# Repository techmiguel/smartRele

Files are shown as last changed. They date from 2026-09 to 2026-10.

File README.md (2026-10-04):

# SmartRele · rele-esp12f

**Single-channel Wi-Fi relay module based on the ESP-12F (ESP8266) for 110–120 VAC mains.**









<p align="center">
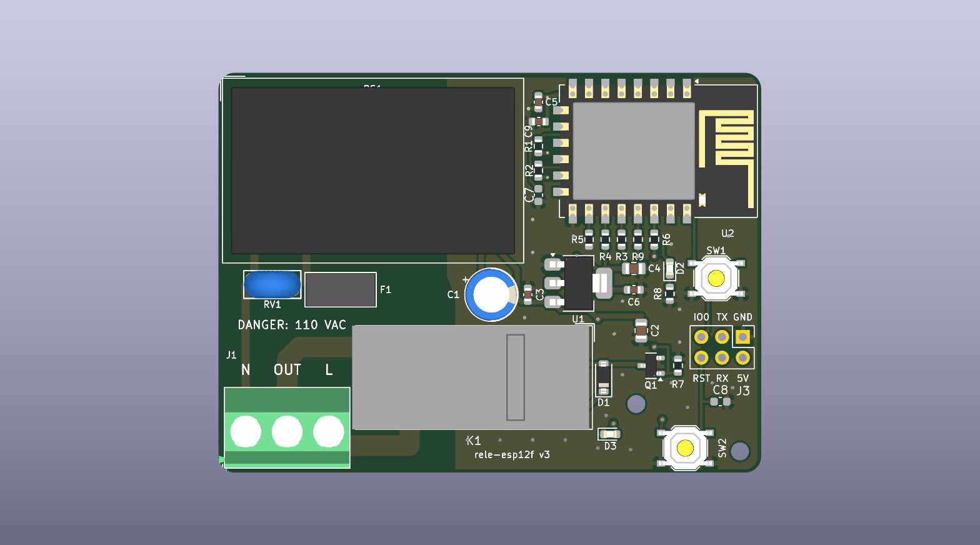
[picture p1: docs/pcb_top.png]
PCB render, top side
  
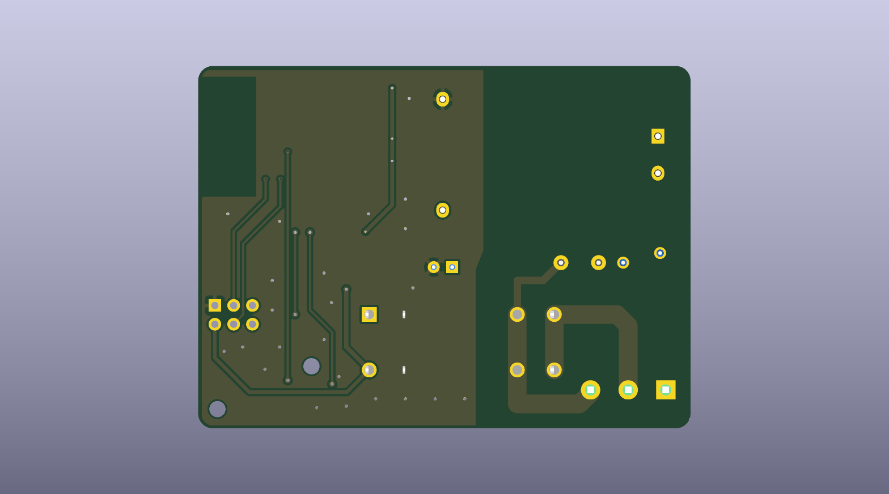
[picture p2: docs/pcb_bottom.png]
PCB render, bottom side
  
</p>

A 2-layer, **66.5 × 49 mm** board that switches a mains load of up to **10 A** from an ESP-12F. It is powered directly from the mains through an isolated HLK-PM01 supply and integrates input protection (time-lag fuse and varistor), a 16 A Omron G5RL power relay, status indicators and a programming header. All components sit on the top side, and the board is ready to be ordered **fully assembled from JLCPCB** (SMD and THT), with no hand soldering.

> [!WARNING]
> This design operates at **mains voltage**. Assembly, testing and installation must be carried out by qualified people. Read the [Safety](#safety) section before connecting the board.

---

## Table of contents
- [Features](#features)
- [Specifications](#specifications)
- [Architecture](#architecture)
- [Connectors and pinout](#connectors-and-pinout)
- [Repository layout](#repository-layout)
- [Manufacturing and assembly](#manufacturing-and-assembly)
- [Firmware](#firmware)
- [First firmware flashing](#first-firmware-flashing)
- [Enclosure](#enclosure)
- [Design verification](#design-verification)
- [Safety](#safety)
- [Documentation](#documentation)
- [License](#license)

## Features
- **ESP-12F** with the antenna at the board edge and a copper-free area underneath.
- **Omron G5RL-1A-E-HR relay** (SPST-NO, 16 A / 250 VAC) with 8 mm coil-to-contact separation (reinforced insulation per the manufacturer).
- **Strict mains / low-voltage zoning** enforced by custom design rules: 4 mm between mains and low voltage, 2 mm between mains nets. Measured minimum clearance: 4.35 mm.
- **Duplicated power path** on both sides (2 × 2.5 mm, 35 µm), sized for 10 A with a ~12 °C temperature rise (IPC-2221).
- **Input protection**: T500mA time-lag fuse (protects the supply) and 07D221K varistor.
- **Robust start-up**: RC delay on EN and RST, 10 µF + 100 nF decoupling next to the module, and the relay held open during reset.
- **Indicators** for relay (red) and Wi-Fi (blue); user/boot (GPIO0) and reset push buttons.
- **Programming** through a 2×3 header powered at 5 V; OTA updates afterwards.
- **Complete manufacturing package**: Gerbers, drill files, BOM and CPL ready for JLCPCB, with 3D models for every part.
- **3D-printable enclosure**, parametric and checked against the 3D model of the assembled board.

## Specifications

| Parameter | Value |
|---|---|
| Input voltage | 110–120 VAC, 50/60 Hz |
| Maximum load | 10 A resistive (trace limit; relay 16 A, terminal block 18 A) |
| Contact | SPST-NO, switches the line (L) |
| On-board supply | HLK-PM01, 5 V / 600 mA, isolated |
| Regulator | AMS1117-3.3 |
| Microcontroller | ESP8266 (ESP-12F module), Wi-Fi 802.11 b/g/n |
| Protection | F1 T500mA 250 V (supply branch) · RV1 07D221K |
| PCB | 66.5 × 49 × 1.6 mm, 2 layers, 35 µm copper |
| Assembly | Single-sided; 32 components, all factory-assembled |
| Mounting holes | 2 × M2 (MH1, MH2), in the low-voltage zone |

The full datasheet, with test conditions and the source of each value, is in [`docs/rele-esp12f_datasheet_user_guide.pdf`](docs/rele-esp12f_datasheet_user_guide.pdf).

## Architecture

```
 Power      J1:L ──────────► K1 contact (COM → NO) ──────────► J1:OUT ──► load

 Supply     J1:L ── F1 ── L_F ──► PS1 HLK-PM01 ──► +5 V ── U1 AMS1117 ──► +3.3 V ──► U2 ESP-12F
                          RV1 between L_F and N

 Control    +5 V ── K1 coil (D1 flyback diode) ── Q1 SS8050 ── GND
                                                   ▲
                                        GPIO5 (U2) ── R6 1 kΩ
```

- **Mains zone** (bottom left): J1, F1, RV1, K1 and the PS1 input.
- **Low-voltage zone** (right): U1 and its capacitors, relay driver, LEDs, push buttons, J3 and mounting holes. GND planes on both sides, restricted to this zone.
- **Top strip**: PS1 on the left and the ESP-12F with its antenna on the right edge.

The full schematic is in [`docs/schematic.pdf`](docs/schematic.pdf).

## Connectors and pinout

### J1 — Mains terminal block (3 poles, 5.08 mm pitch)
| Pin | Signal | Function |
|:-:|---|---|
| 1 | N | Neutral |
| 2 | OUT | Switched output to the load |
| 3 | L | Line input |

### J3 — Programming (2×3 header, 2.54 mm pitch)
```
 IO0   TX   GND(1)
 RST   RX   5V
```
Pin 1 (square pad) = GND; pin 2 = 5 V. Labeled on the silkscreen.

### ESP-12F
| GPIO | Function |
|---|---|
| GPIO5 | Relay (SS8050, R6 1 kΩ, R7 10 kΩ to GND) and relay LED (D2) |
| GPIO4 | Wi-Fi LED (D3) |
| GPIO0 | Push button SW1 (flashing mode / application use), 10 kΩ to 3.3 V |
| GPIO2 | 10 kΩ to 3.3 V (boot strap) |
| GPIO15 | 10 kΩ to GND (boot strap) |
| EN, RST | 10 kΩ to 3.3 V + 100 nF to GND; RST also to SW2 |

## Repository layout

```
.
├── rele-esp12f.kicad_pro      KiCad 10 project
├── rele-esp12f.kicad_sch      Schematic
├── rele-esp12f.kicad_pcb      PCB layout
├── rele-esp12f.kicad_dru      Custom design rules (mains isolation)
├── 3dmodels/                  STEP models missing from the KiCad library (K1, F1, SW1/SW2)
├── fabrication/               Production package for JLCPCB
│   ├── gerbers/               Gerbers and drill files (Excellon)
│   ├── gerbers_JLCPCB.zip     Gerbers + drill files + CPL, ready to upload
│   ├── BOM_JLCPCB.csv         Bill of materials with LCSC part numbers
│   └── CPL_JLCPCB.csv         Component placement list
├── docs/
│   ├── schematic.pdf
│   ├── rele-esp12f_datasheet_user_guide.pdf
│   ├── pcb_top.png · pcb_bottom.png
│   └── datasheets/            Datasheets of the key components
├── firmware/                  ESP8266 firmware (PlatformIO, Arduino core)
├── enclosure/                 3D-printable enclosure (FreeCAD, STEP, STL)
├── scripts/                   PDF datasheet generator
├── CHANGELOG.md
└── LICENSE
```

The custom 3D models are referenced through `${KIPRJMOD}/3dmodels/`, so the project opens without any extra path configuration.

## Manufacturing and assembly

1. Upload [`fabrication/gerbers_JLCPCB.zip`](fabrication/gerbers_JLCPCB.zip) to JLCPCB (2 layers, 1.6 mm).
2. Enable **PCB Assembly** (top side) and upload [`BOM_JLCPCB.csv`](fabrication/BOM_JLCPCB.csv) and [`CPL_JLCPCB.csv`](fabrication/CPL_JLCPCB.csv).
3. Before paying, check in the JLCPCB viewer that:
   - U2 and K1 sit on their pads;
   - the J1 wire entry faces the board edge;
   - J3 pin 1 lands on the square pad (GND);
   - every BOM line has a part selected.

THT parts are wave-soldered. The CPL uses the **pad center** (JLCPCB convention), not the body center; for U2 and K1 they differ. The drill holes of J1 (Ø1.5 mm) and RV1 (Ø1.0 mm) are matched to the actual parts.

### Power and THT components

| Ref. | Part | LCSC | Notes |
|---|---|---|---|
| PS1 | Hi-Link HLK-PM01 | C209903 | Isolated 5 V supply |
| K1 | Omron G5RL-1A-E-HR DC5 | C113250 | SPST-NO 16 A; 5 V coil, 80 mA |
| F1 | Reomax MTS0500A, T500mA 250 V | C2762401 | Time-lag, due to the PS1 inrush current |
| RV1 | Varistor 07D221K | C49072913 | For 110–120 VAC |
| C1 | 470 µF 10 V | C112505 | |
| J1 | KANGNEX WJ500V-5.08-3P | C72334 | 250 V / 18 A |
| J3 | 2×3 header, 2.54 mm | C65114 | Only used for the first flashing |

The full list is in the [BOM](fabrication/BOM_JLCPCB.csv).

### Regenerating the production files

With `kicad-cli` (KiCad 10), from the repository root:

```bash
kicad-cli pcb export gerbers --layers F.Cu,B.Cu,F.SilkS,B.SilkS,F.Mask,B.Mask,F.Paste,Edge.Cuts -o fabrication/gerbers/ rele-esp12f.kicad_pcb
```

```bash
kicad-cli pcb export drill --format excellon --excellon-units mm --excellon-separate-th --excellon-zeros-format decimal -o fabrication/gerbers/ rele-esp12f.kicad_pcb
```

```bash
kicad-cli pcb render --side top -w 1592 -h 904 --background opaque --quality basic --zoom 0.9954 -o docs/pcb_top.png rele-esp12f.kicad_pcb
```

```bash
kicad-cli pcb render --side bottom -w 1592 -h 904 --background opaque --quality basic --zoom 0.9954 -o docs/pcb_bottom.png rele-esp12f.kicad_pcb
```

These explicit options are needed because the plot settings stored in the board produce `.gbr` extensions and an unnecessary B.Paste layer. The ZIP contains the 11 files in `fabrication/gerbers/` plus `CPL_JLCPCB.csv`.

## Firmware

The [`firmware/`](firmware/) folder holds the board's own firmware (PlatformIO, Arduino core for ESP8266). In this version the relay is controlled over Wi-Fi only, from a built-in web page or a JSON REST API:

- manual on / off;
- state-change timer (turn on, off or toggle after 1 s – 7 days);
- cyclic ON/OFF routine (on for one period, off for another, repeated);
- up to 16 weekly schedules synchronised over NTP, with a configurable time zone.

On first boot it opens the `SmartRele-XXXXXX` setup access point; holding SW1 for 8 s erases the Wi-Fi settings. Setup, behaviour, API and security notes are in [`firmware/README.md`](firmware/README.md).

## First firmware flashing

1. **Disconnect the board from mains.**
2. Connect a USB-serial adapter with **3.3 V logic** to J3: TX↔RX, RX↔TX, GND, and its **5 V (VBUS)** output to the 5V pin.
3. Hold SW1 (GPIO0) while pressing and releasing SW2 (RST) to enter flashing mode.
4. Flash the firmware (`pio run -e esp12f -t upload` from `firmware/`). Later updates are done over the air (OTA).

J3 is powered at 5 V rather than 3.3 V for two reasons. The internal output-to-input diode of the AMS1117 would make the adapter also feed the 5 V rail. In addition, the 3.3 V pin of a typical adapter cannot supply the current peaks the ESP8266 draws while calibrating its radio.

Third-party firmware also works: the [datasheet](docs/rele-esp12f_datasheet_user_guide.pdf) includes example configurations for Tasmota and ESPHome.

## Enclosure

The [`enclosure/`](enclosure/) folder contains a two-part enclosure (base and screwed lid) for 3D printing in PETG or ASA/ABS. It is generated by a parametric FreeCAD script, and its interference with the 3D model of the assembled board is zero. Design, printing and assembly details are in [`enclosure/README.md`](enclosure/README.md).

<p align="center">
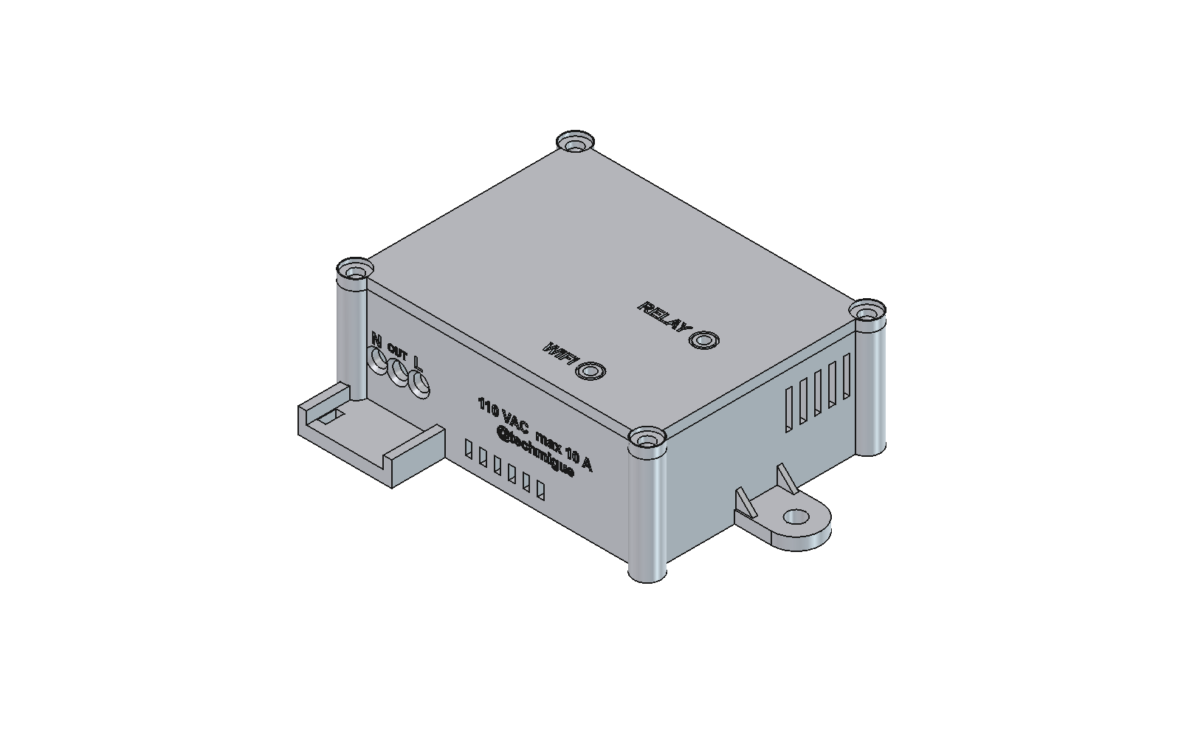
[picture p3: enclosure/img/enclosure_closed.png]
Closed enclosure
  
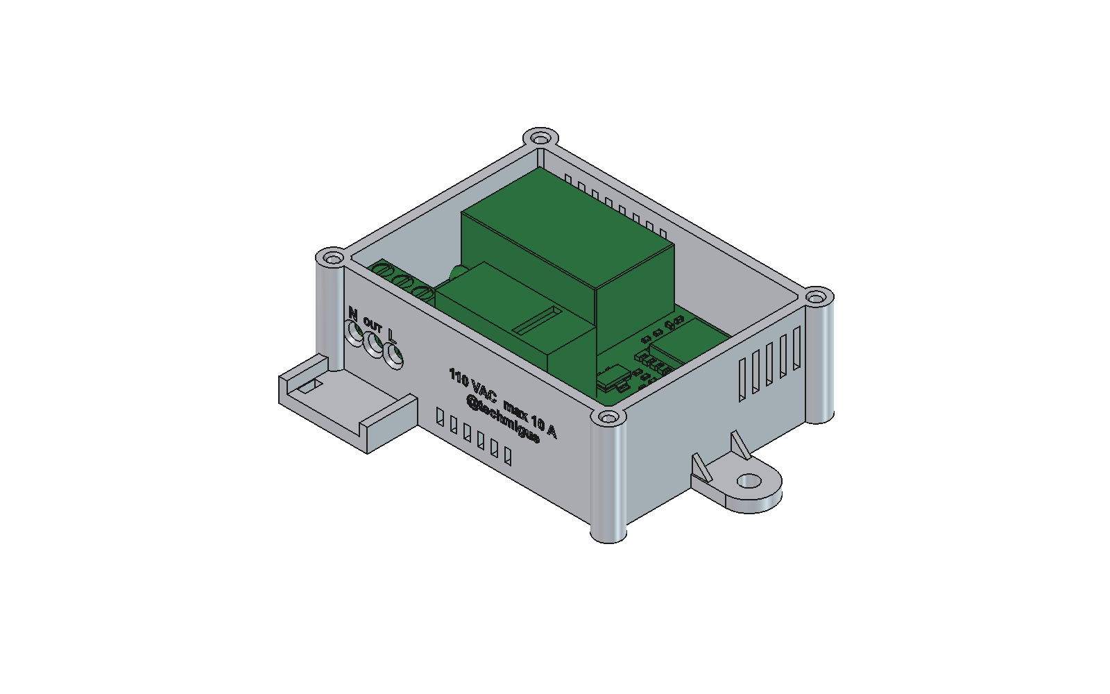
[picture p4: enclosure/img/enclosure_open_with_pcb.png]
Open enclosure with the board
  
</p>

## Design verification

Results with `kicad-cli` 10.0.5, with all zones refilled:

| Check | Errors | Warnings | Warning details |
|---|:-:|:-:|---|
| DRC | **0** | 29 | 23 footprints modified from the library (J1/RV1 drills and custom 3D models); 6 PS1/J1 silkscreen items next to the rounded corners |
| Schematic ↔ PCB parity | **0** | 34 | 32 LCSC/assembly fields not copied to footprints; 2 mounting holes without a symbol |
| ERC | **0** | 9 | Off-grid endpoints and symbols that differ from the library |
| Unconnected pads | **0** | — | |

None of the warnings affects manufacturing. Measured clearances: mains copper ↔ low voltage ≥ 4.35 mm on both sides; mains copper ↔ board edge ≥ 2.0 mm.

## Safety

- **110–120 VAC mains.** The 07D221K varistor is rated for that voltage. For 230 VAC it must be replaced (e.g. with a 07D471K). F1 is suitable for both voltages.
- **The load current does not flow through F1**, which only protects the supply. Install a circuit breaker or fuse of **≤ 10 A** upstream, dedicated to this output. An on-board fuse would not have enough breaking capacity for a mains short circuit.
- **Never connect J3 while the board is connected to mains.**
- Mount the board in an **insulating enclosure**: mains copper is 2 mm from the board edge.
- Use only **MH1 and MH2** (low-voltage zone) for metal hardware: M2 screws with a head or washer of Ø ≤ 5 mm.
- The printed enclosure provides mechanical and contact protection, but it is **not certified**. For a permanent installation, print it in a flame-retardant material or place it inside an approved electrical junction box.

## Documentation

| Document | Contents |
|---|---|
| [Datasheet and user guide](docs/rele-esp12f_datasheet_user_guide.pdf) | Specifications, operation, installation and design rationale |
| [Schematic](docs/schematic.pdf) | Full schematic in PDF |
| [Datasheets](docs/datasheets/) | Omron G5RL, AMS1117, ESP8266EX, ESP-WROOM-02 and the Espressif hardware design guidelines |
| [Changelog](CHANGELOG.md) | Hardware revisions and the rationale behind each change |
| [Enclosure](enclosure/README.md) | Enclosure design, printing and assembly |

The datasheet is regenerated with `python scripts/generate_datasheet.py` (requires ReportLab, PyMuPDF, Pillow and `kicad-cli`).

## License

Hardware released under the **CERN Open Hardware Licence v2 – Weakly Reciprocal** ([CERN-OHL-W-2.0](LICENSE)).

Inspired by [aman983/ESP-01S_Relay_Module](https://github.com/aman983/ESP-01S_Relay_Module). This is a new design and contains no files from the original.

---

© 2026 [@techmigue](https://github.com/techmiguel)

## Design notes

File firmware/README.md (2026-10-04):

# SmartRele firmware · rele-esp12f

Firmware v1.0.0 for the rele-esp12f board (ESP-12F / ESP8266). The relay is **controlled over Wi-Fi only**, from a built-in web interface or through a JSON REST API:

- **Manual on / off.**
- **State-change timer**: after a delay (1 s to 7 days) it turns the relay on, off or toggles it.
- **Cyclic ON/OFF routine**: on for one period and off for another, repeated indefinitely.
- **Weekly schedules**: up to 16 rules of the form "at HH:MM, on these days, turn on/off/toggle".

Push button SW1 does not control the relay in this version: it only erases the Wi-Fi settings.

## Hardware used

| GPIO | Function | Active level |
|---|---|---|
| GPIO5 | Relay K1 (through Q1) and red LED D2 | High |
| GPIO4 | Blue LED D3 (Wi-Fi status) | High |
| GPIO0 | Push button SW1 (R3 to 3.3 V) | Low |

Pins checked against the schematic netlist. R7 (10 kΩ to GND) keeps the relay open while GPIO5 is high-impedance (reset, boot and flashing); the firmware also drives the pin low as its very first instruction.

## Build and flash

Requires [PlatformIO](https://platformio.org/) (CLI or the VS Code extension). From this folder:

```bash
pio run -e esp12f
```

First flashing through header J3 (see the [main README](../README.md#first-firmware-flashing): board **disconnected from the mains**, 3.3 V USB-serial adapter, J3 powered at 5 V, hold SW1 while releasing SW2):

```bash
pio run -e esp12f -t upload
```

Serial monitor (115200 baud), useful to see the IP address and relay events:

```bash
pio device monitor
```

### Over-the-air updates (OTA)

Once the device is on the network there are two options, both protected by the admin password:

- **Browser**: *System → Update firmware* (`http://<device>/update`) and upload `.pio/build/esp12f/firmware.bin`.
- **PlatformIO** (ArduinoOTA): set the environment variable `SMARTRELE_PASS` to the admin password and run:

```bash
pio run -e esp12f_ota -t upload --upload-port smartrele-xxxxxx.local
```

The relay keeps its state while the update is written. The restart that follows briefly releases it, and then the *state at power-up* setting (or the cyclic routine, if it was active) is applied.

## Getting started

1. With no network configured, the device creates the access point **`SmartRele-XXXXXX`** (password `smartrele`). The blue LED blinks fast.
2. Join it from a phone. The setup page opens by itself; if it does not, browse to `http://192.168.4.1`.
3. Under *Settings*, set an **admin password** (user `admin`, 8–32 characters) and the time zone.
4. Under *Wi-Fi network*, pick the network, enter its password and press *Save and restart*.
5. The device joins the network (blue LED steady) and is reachable at `http://smartrele-xxxxxx.local/` (mDNS) or at the IP address the router assigns (shown on the serial monitor and in the router).

`XXXXXX` is the chip ID in hexadecimal, different on every board.

If the network is unavailable for 60 s, the access point opens again (the device keeps retrying the network) so the settings can be changed. It closes as soon as the network is back and nobody is connected to it.

**Erasing the Wi-Fi network**: hold SW1 for **8 s** (from 3 s on, the blue LED blinks very fast). The device restarts in access point mode. Schedules and the password are kept; to erase everything use *Factory reset* in the web interface.

### Blue LED (D3)

| Pattern | Meaning |
|---|---|
| Steady | Connected to the Wi-Fi network |
| Short flash every second | Looking for the network |
| Fast blink (2 Hz) | Setup access point active |
| Very fast blink | SW1 held: at 8 s the network is erased |

The red LED (D2) is wired in parallel with the relay driver: lit = relay closed.

## Behaviour

### Priorities between automations

| Command | Cyclic routine | Timer |
|---|---|---|
| Manual (web/API) | Stops it | Keeps running |
| Weekly schedule | Stops it | Keeps running |
| Start timer | Stops it | — |
| Start cyclic routine | — | Cancels it |

The timer and the cyclic routine cannot be active at the same time. When the timer expires it runs its action once.

### Time and schedules

- The time comes from **NTP** (`pool.ntp.org` by default) and is converted to local time with the configured **POSIX time zone** (the web interface lists those of Latin America, the US and Europe; any other can be typed in). The default is UTC.
- Without Internet access (for example, using only the access point) the web page sends the browser time when it opens. NTP time always takes precedence.
- Schedules do not run until the time is valid; the timer and the cyclic routine do, because they only use the internal clock.
- Each schedule runs once in its minute. After a restart it only runs if the device boots within the first 10 s of that minute. Schedules missed during a power cut are not caught up.
- When daylight saving time ends, a schedule inside the repeated hour may run twice.

### After a power cut

| Situation when power returns | Behaviour |
|---|---|
| Cyclic routine active | Resumes, starting with the ON phase |
| *State at power-up* = Off (default) | Relay open |
| = On | Relay closed |
| = Last state | State before the power cut |

The timer does **not** survive a restart. Schedules, the cyclic routine and the settings are stored in flash (LittleFS). The last relay state is only written when it changes, and never during the cyclic routine, to avoid wearing out the flash.

### Limits

| Parameter | Range |
|---|---|
| Timer | 1 s – 7 days |
| Cyclic routine phase | 5 s – 24 h |
| Schedules | 16 |

The 5 s minimum per phase prevents absurdly fast switching, but it is not enough for the relay to last: the Omron datasheet guarantees **50,000–100,000 electrical operations** at rated load (depending on the model). A 5 s ON / 5 s OFF routine makes 360 operations per hour and would use up 50,000 in less than a week; a 10 min ON / 50 min OFF routine would take more than five years. Choose phases as long as the application allows.

## REST API

All routes take and return JSON. When an admin password is set, **HTTP Digest** authentication is used with user `admin`. Examples with `curl`:

```bash
curl --digest -u admin:PASSWORD http://smartrele-xxxxxx.local/api/status
```

```bash
curl --digest -u admin:PASSWORD -X POST -H "Content-Type: application/json" -d '{"action":"on"}' http://smartrele-xxxxxx.local/api/relay
```

| Method and route | Body | Function |
|---|---|---|
| `GET /api/status` | — | Full status: relay, timer, routine, schedules, next event, time, Wi-Fi and system |
| `POST /api/relay` | `{"action":"on"\|"off"\|"toggle"}` | Direct command |
| `POST /api/timer` | `{"seconds":1800,"action":"off"}` | Starts the timer (`action` defaults to `off`) |
| `DELETE /api/timer` | — | Cancels the timer |
| `POST /api/cycle` | `{"on":600,"off":3000}` | Starts the cyclic routine (seconds) |
| `DELETE /api/cycle` | — | Stops the cyclic routine |
| `GET /api/schedules` | — | List of schedules |
| `POST /api/schedules` | `{"time":"07:30","days":62,"action":"on","enabled":true}` | Adds a schedule |
| `PUT /api/schedules?id=N` | Any field of the above | Modifies schedule N (0-based index) |
| `DELETE /api/schedules?id=N` | — | Deletes schedule N |
| `GET /api/config` | — | Settings (without passwords) |
| `POST /api/config` | `{"name","tz","ntp","powerOn":0\|1\|2,"adminPass"}` | Changes settings; every field is optional |
| `POST /api/time` | `{"epoch":1767225600}` | Sets the clock when there is no NTP |
| `GET /api/wifi/scan` | — | Scans for networks (replies 202 while scanning) |
| `POST /api/wifi` | `{"ssid":"...","pass":"..."}` | Stores the network and restarts |
| `POST /api/reboot` | — | Restarts |
| `POST /api/factory-reset` | — | Erases all settings and restarts |

`days` is a bit mask with Sunday in bit 0: Monday to Friday = 62, weekends = 65, every day = 127.

Changing the admin password restarts the device, because ArduinoOTA and `/update` read it at boot.

## Security

- **Always set an admin password.** Without it, anyone on the network (or on the access point, whose password is public) can switch the relay.
- The web interface uses plain HTTP. Digest authentication does not send the password in clear text, but the rest of the traffic is unencrypted: use it only on your local network and do not expose it to the Internet by forwarding ports on the router.
- Passwords are stored unencrypted in the module flash. Anyone with physical access to the board can read them.
- **Never connect the serial adapter to J3 while the board is connected to the mains.**

## Layout

```
firmware/
├── platformio.ini     esp12f (serial) and esp12f_ota (network) environments
└── src/
    ├── main.cpp       Start-up and main loop
    ├── board.h        Pin assignment
    ├── settings.*     Persistent settings (LittleFS, JSON)
    ├── relay.*        Relay, timer and cyclic routine
    ├── scheduler.*    Time (NTP / time zone) and weekly schedules
    ├── network.*      Wi-Fi, access point, captive portal, mDNS, OTA, LED and SW1
    ├── web.*          HTTP server and REST API
    └── web_ui.h       Embedded web interface
```

Dependencies: Arduino core for ESP8266 (PlatformIO `espressif8266` platform) and [ArduinoJson](https://arduinojson.org/) 7, which PlatformIO downloads automatically.

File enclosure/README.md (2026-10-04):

# 3D-printable enclosure — rele-esp12f v3

Two-part enclosure: base and screwed lid. Designed in FreeCAD from the real 3D model of the assembled PCB.

<p align="center">
  Closed enclosure
  Open enclosure with the PCB
</p>
<p align="center">
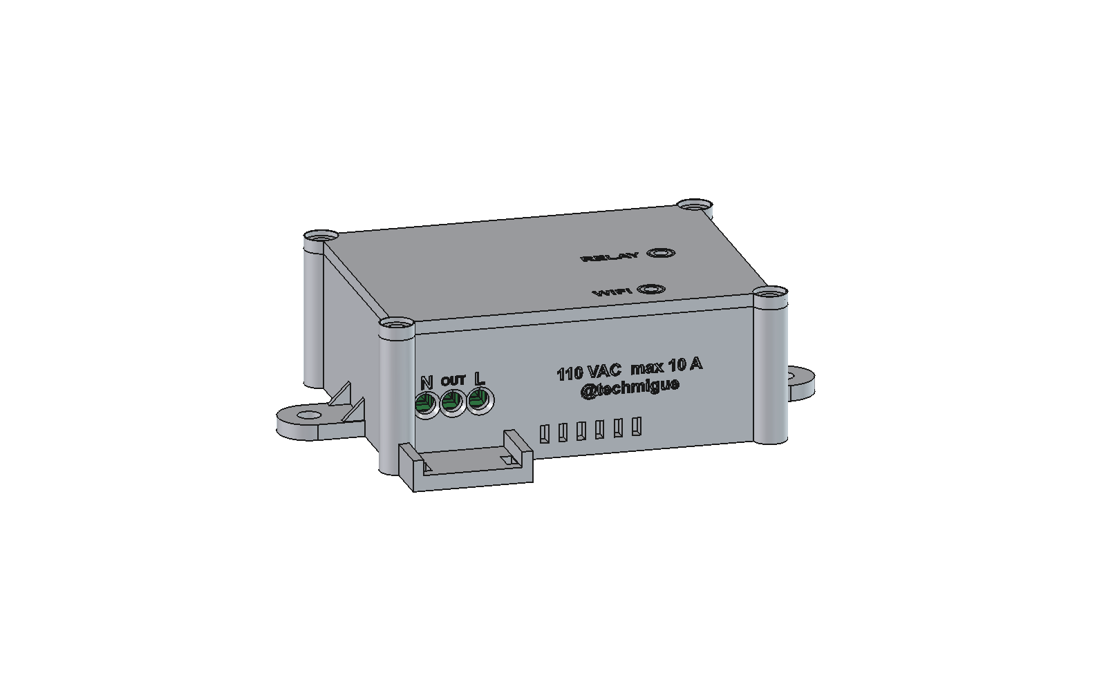
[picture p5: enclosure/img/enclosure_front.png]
Front view: cable entries and labels
  
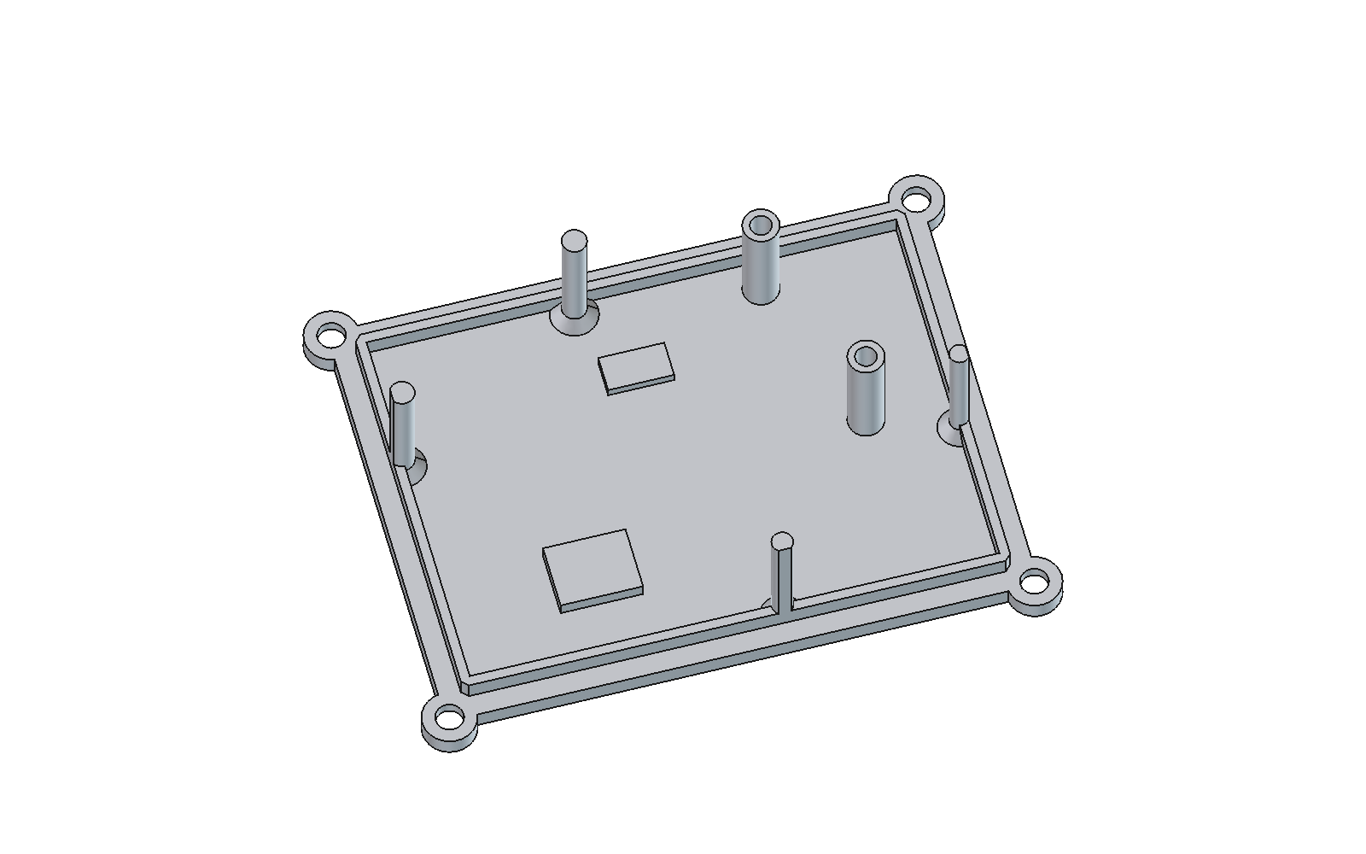
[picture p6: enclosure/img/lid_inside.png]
Inside of the lid: hold-down posts and light pipes
  
</p>

## Files
| File | Contents |
|---|---|
| `stl/enclosure_base.stl` | Base, already oriented for printing (floor on the bed). |
| `stl/enclosure_lid.stl` | Lid, already flipped (top face on the bed). |
| `enclosure_rele-esp12f.FCStd` | FreeCAD document with the parts in assembly position and the reference PCB. |
| `enclosure_rele-esp12f_assembly.step` | Base and lid in assembly position, without the PCB. |
| `rele-esp12f_pcb.step` | Assembled PCB exported from KiCad. Used to check the fit. |
| `generate_enclosure.py` | Parametric script that generates all of the above. |
| `img/` | Renders: closed, open with PCB, front, top, bottom and lid inside. |

To regenerate, from the repository root:
```bash
kicad-cli pcb export step --subst-models --force --user-origin 100x149mm -o enclosure/rele-esp12f_pcb.step rele-esp12f.kicad_pcb
```
```bash
freecadcmd enclosure/generate_enclosure.py
```
It can also be run from the FreeCAD Python console (with the repository root as the working directory): `exec(open(r"enclosure/generate_enclosure.py", encoding="utf-8").read())`.

## Dimensions
- Outside: 77.5 × 60 × 28.5 mm (box only; 101.9 × 70.2 mm including the mounting tabs and the strain-relief apron).
- Inside: 67.1 × 49.6 mm, i.e. the PCB plus 0.3 mm of clearance per side. 2.4 mm walls, 2.0 mm floor and 2.5 mm lid.
- PCB 5 mm above the floor. The longest THT leads (PS1) protrude 3.3 mm below the board, leaving a 1.7 mm air gap.
- Ceiling 1.7 mm above relay K1, the tallest part (15.7 mm above the PCB).

## Design criteria
- **Measured fit, not estimated.** Every dimension comes from the STEP exported by KiCad. The script checks the intersection of each part with the 87 solids of the assembled PCB: the interference volume is **0**. J3 has no 3D model in the library, so it was checked by hand: its pins reach about 17 mm and the lid starts at 23.5 mm (skirt).
- **PCB retention.** The board only has two mounting holes (MH1 and MH2), both in the bottom-right corner. With only two screws the board could rotate or lift on the mains side. Therefore:
  - Below, it rests on a 1.5 mm perimeter ledge (supporting 1.2 mm of the board edge), on the M2 standoffs of MH1/MH2 and on two pillars located right under SW1 and SW2, so the board does not flex when they are pressed with the lid removed.
  - Above, four lid posts come down to 0.2 mm from the PCB in component-free areas: left edge between J1 and PS1, top edge between PS1 and the ESP, bottom edge under K1 and right edge next to SW1. Two more stops sit 0.5 mm above PS1 and K1. Even if the screws loosen, the board cannot move more than 0.2 mm.
  - Metal screws only go through MH1/MH2. These holes are in the low-voltage zone, as required by the PCB README.
- **Screwed lid (4 × M3), not snap-fit.** On mains equipment, opening the enclosure must require a tool. The screw bosses are outside the PCB outline, 0.64 mm from its rounded corners. A 2.5 mm skirt centers the lid on the base.
- **Mains entry.** Three Ø3.8 mm holes with an outer countersink, aligned with the J1 wire entries. They were measured on the 3D model: center 5.1 mm above the PCB bottom face and 5.08 mm pitch. They are labeled N · OUT · L, matching the terminal block. In front there is an apron with two slots for a cable tie that provides strain relief: pulling the cable must never reach the terminal block.
- **No buttons on the lid.** SW1 (GPIO0) and SW2 (RST) are for debugging only: they stay inside and are pressed with the lid removed. Every hole and moving part removed from a mains enclosure is one less entry path for dust or objects. If the firmware used SW1 to toggle the relay by hand, a guide and a plunger above SW1 would have to be added to the lid.
- **LEDs.** D2 and D3 are 0603 SMD parts, 1.1 mm above the PCB. Ø2.6 mm light pipes come down from the lid to 1.5 mm above each LED, so the light of one LED is not visible through the other's hole. The holes stay above the LEDs, which are placed diagonally (7.3 mm in X and 20.3 mm in Y). To keep the marking tidy without moving them, the same module is repeated for each LED:
  - an engraved ring concentric with the hole, from Ø4.2 to Ø5.2 mm;
  - the label (RELAY / WiFi), same size (2.6 mm), right-aligned at the same distance from the ring and vertically centered on the hole.
  For better visibility, the pipe can be filled with a drop of clear resin or a piece of clear 1.75 mm filament.
- **Convection cooling.** Air enters through low slots at the front (below the PCB, next to the relay) and leaves through high slots at the back (above PS1) and on the right side. All slots are **1.5 mm** wide, so a 2.5 mm probe cannot pass (IP3X in that respect; not tested).
- **Antenna.** Only plastic covers the ESP-12F antenna; there are no screws or metal parts in that area. The mounting tabs are at both ends: the right-hand hole is 11.7 mm from the PCB edge, at mid-height of the board.

## Labels (engraved 0.5–0.6 mm deep)
- Lid: only RELAY and WiFi, next to their LEDs.
- Front: N · OUT · L above the cables and, below, on two lines, "110 VAC  max 10 A" and "@techmigue".
- Bottom: "Smart Rele" (product name), readable when the enclosure is turned over.

## Printing
- **Material: PETG or ASA/ABS.** Not PLA: inside the enclosure, PS1 and the relay coil (~0.5 W) produce heat, and PLA deforms from about 55 °C.
- 0.2 mm layers, 4 perimeters (the 2.4 mm walls come out solid), 25–30 % gyroid infill. **No supports needed**: all overhangs are bridges of ≤ 3.8 mm or 45° chamfers.
- The STL meshes were verified to be closed, with no non-manifold edges and no self-intersections.

## Assembly
Hardware: 4 × M3×10 self-tapping (lid), 2 × M2×6 self-tapping (PCB), 2 × M4 to mount the enclosure and 1 × 3.6 mm cable tie.
1. Screw the PCB to the base through MH1 and MH2 (M2×6, do not overtighten: it is plastic).
2. Pass the cables through the front holes and tighten them in J1 (N · OUT · L, left to right seen from the front). Secure them to the apron with the cable tie.
3. Close the lid and fit the 4 M3 screws.

## Safety notes (read)
- Common filaments (PETG, ASA, ABS) are **not self-extinguishing** (not UL94 V-0). For a permanent mains installation, the correct practice is one of:
  - printing in a flame-retardant material (PC-FR, ABS-FR or PETG V0);
  - placing this enclosure inside an approved electrical junction box.
  This enclosure provides mechanical and contact protection, but it is not certified.
- **Do not connect the USB-serial adapter (J3) while the board is connected to mains.** J3 is deliberately left inside the enclosure: it is only used with the lid removed and mains disconnected.
- Overcurrent protection for the load must still be installed upstream: a circuit breaker or fuse of ≤ 10 A (see the project README).

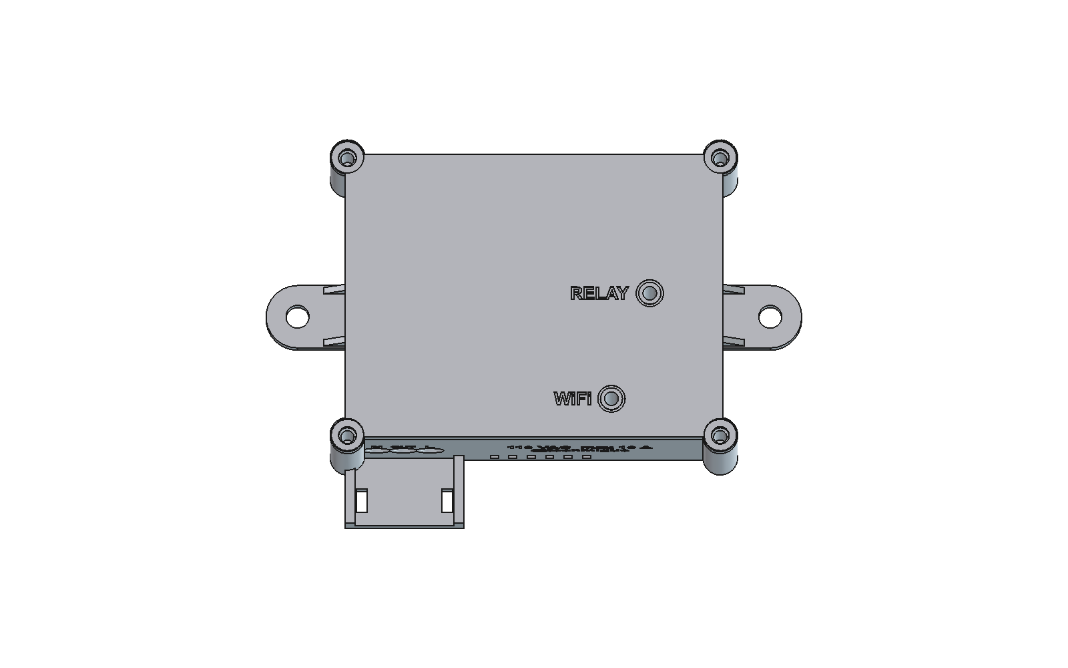
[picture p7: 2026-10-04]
enclosure/img/enclosure_top.png

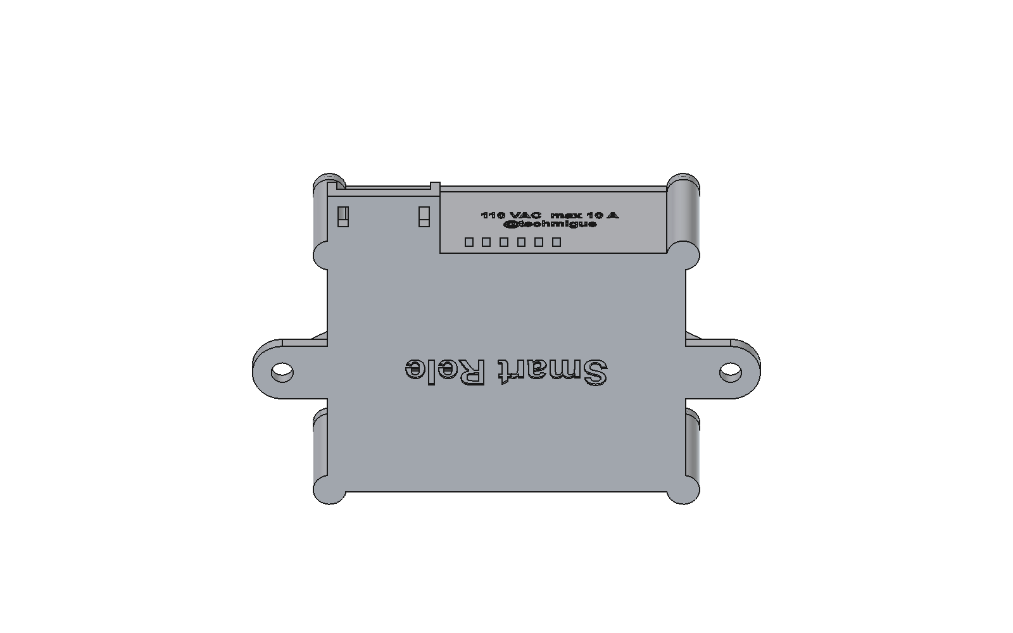
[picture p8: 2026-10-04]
enclosure/img/enclosure_bottom.png

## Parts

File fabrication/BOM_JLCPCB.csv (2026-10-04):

Comment | Designator | Footprint | LCSC Part #
22uF 10V | C2,C4 | C_0805_2012Metric | C45783
10uF 10V X5R | C9 | C_0603_1608Metric | C19702
100nF | C3,C5,C6,C7,C8 | C_0603_1608Metric | C14663
1N4148W | D1 | D_SOD-123 | C81598
LED relay (red) | D2 | LED_0603_1608Metric | C2286
LED WiFi (blue) | D3 | LED_0603_1608Metric | C51933294
SS8050 | Q1 | SOT-23 | C2150
10k | R1,R2,R3,R4,R5,R7 | R_0603_1608Metric | C25804
1k | R6,R8 | R_0603_1608Metric | C21190
220 | R9 | R_0603_1608Metric | C22962
TS-1187A | SW1,SW2 | SW_Push_1P1T_XKB_TS-1187A | C318884
AMS1117-3.3 | U1 | SOT-223-3_TabPin2 | C6186
470uF 10V | C1 | CP_Radial_D6.3mm_P2.50mm | C112505
T500mA 250V (Reomax MTS0500A; time-lag) | F1 | Fuse_Littelfuse_395Series | C2762401
G5RL-1A-E-HR DC5 (Omron, 16 A, SPST-NO) | K1 | Relay_SPST_Omron_G2RL-1A-E | C113250
HLK-PM01 | PS1 | Converter_ACDC_Hi-Link_HLK-PMxx | C209903
07D221K | RV1 | RV_Disc_D7mm_W3.4mm_P5mm | C49072913
ESP-12F | U2 | ESP-12E | C82891
N / L_OUT / L_IN (terminal block 3P 5.08 mm) | J1 | TerminalBlock_Phoenix_MKDS-1,5-3-5.08_1x03_P5.08mm_Horizontal | C72334
PROG (header 2x3 2.54 mm) | J3 | PinHeader_2x03_P2.54mm_Vertical | C65114

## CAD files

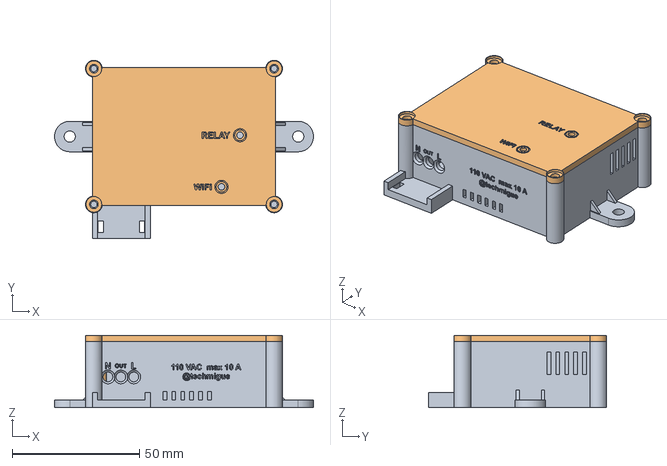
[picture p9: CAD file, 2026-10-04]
enclosure/enclosure_rele-esp12f_assembly.step
101.9 x 70.2 x 28.5 mm

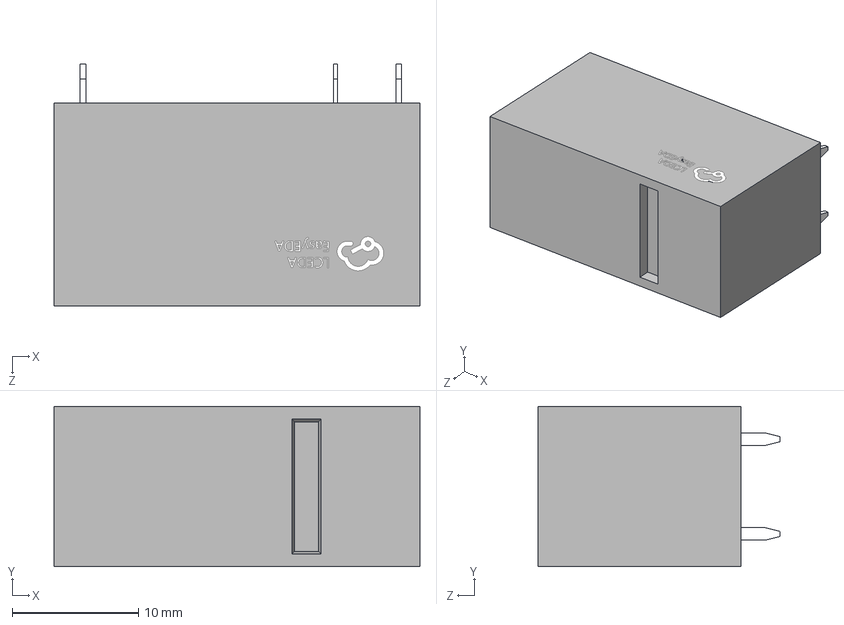
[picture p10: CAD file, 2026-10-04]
3dmodels/Relay_Omron_G5RL-1A-E-HR_C113250.step
29.0 x 12.7 x 19.2 mm

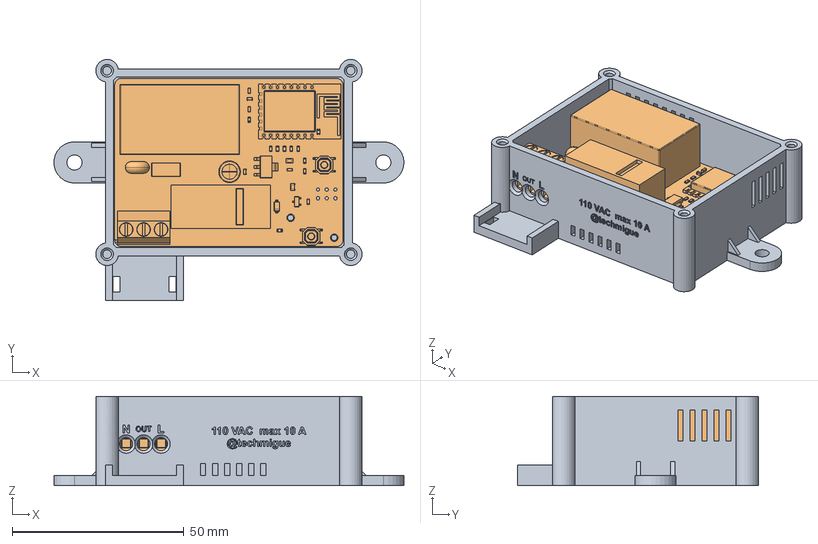
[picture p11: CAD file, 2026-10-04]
enclosure/enclosure_rele-esp12f.FCStd
101.9 x 70.2 x 26.0 mm
Base
PCB_reference

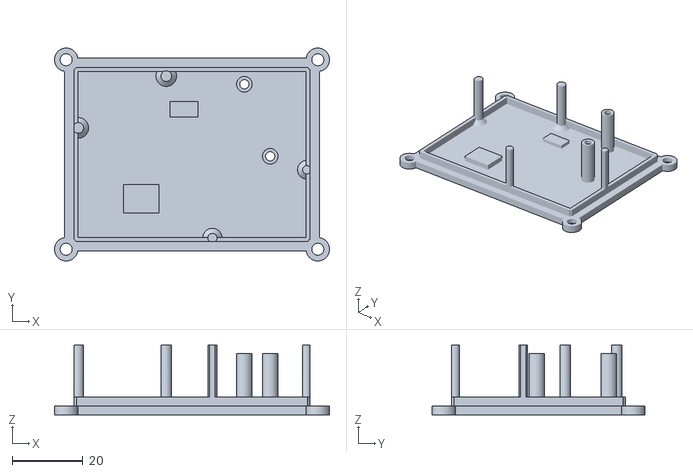
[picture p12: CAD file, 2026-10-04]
enclosure/stl/enclosure_lid.stl
77.5 x 60.0 x 19.7

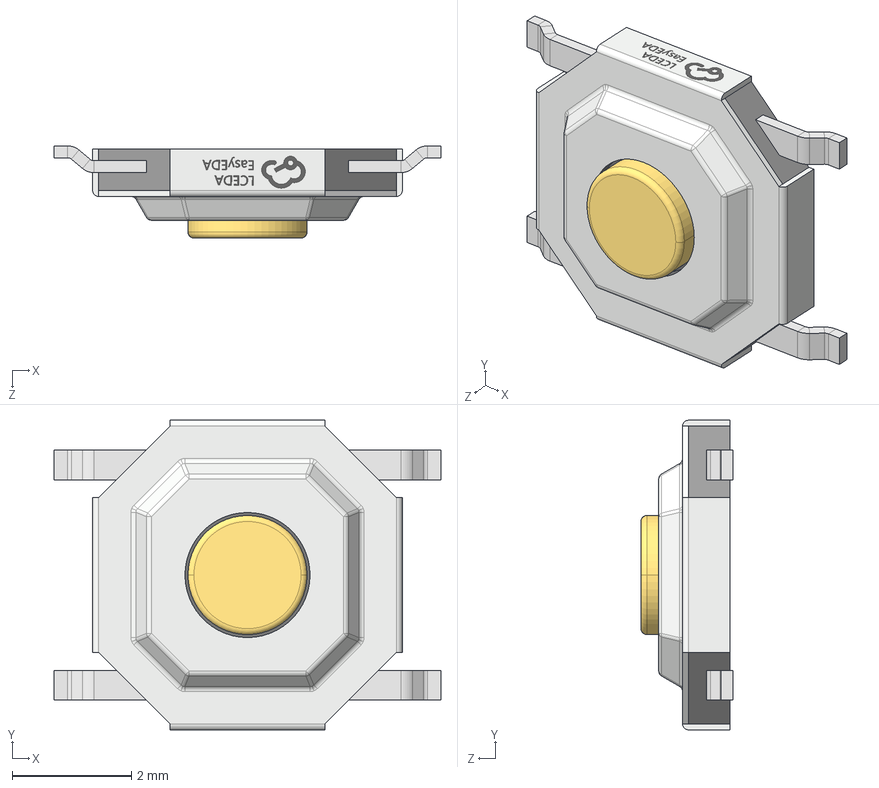
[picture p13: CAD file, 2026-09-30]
3dmodels/SW_TS-1187A_C318884.step
6.50 x 5.20 x 1.55 mm

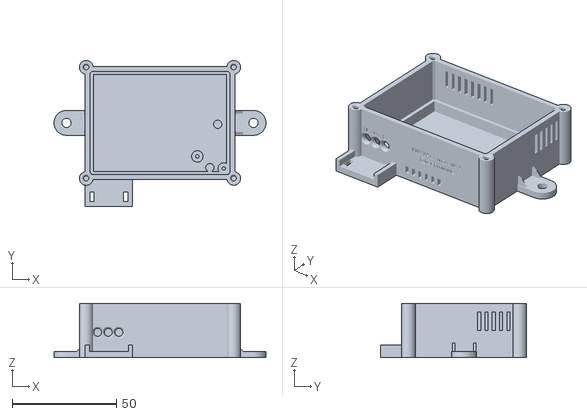
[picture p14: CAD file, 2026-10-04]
enclosure/stl/enclosure_base.stl
101.9 x 70.2 x 26.0

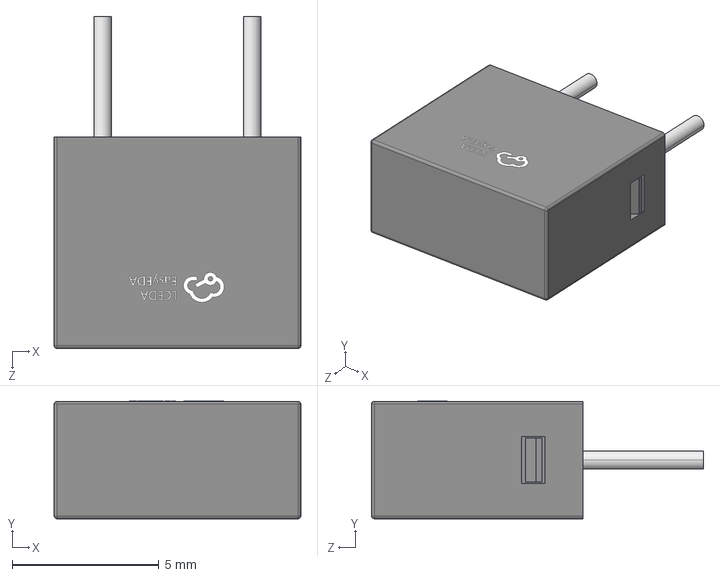
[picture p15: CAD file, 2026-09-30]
3dmodels/Fuse_Reomax_MTS_C2762401.step
8.40 x 4.00 x 11.3 mm

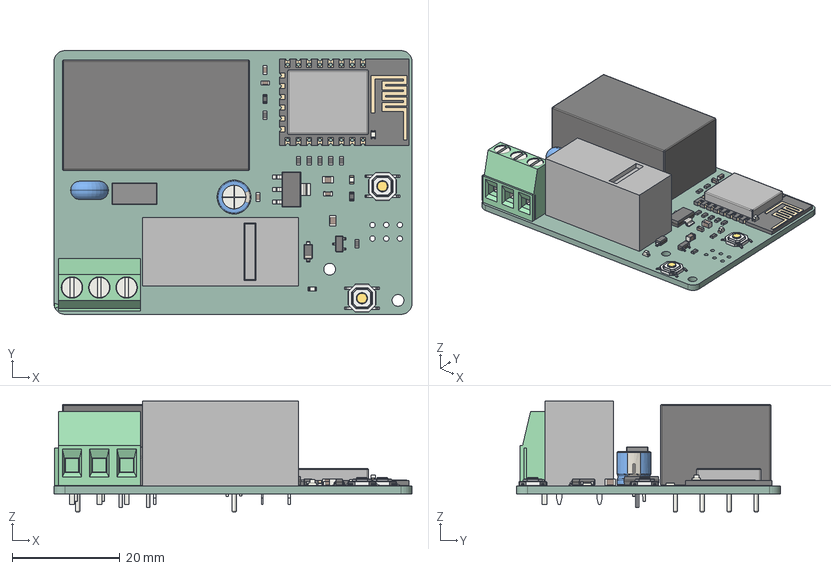
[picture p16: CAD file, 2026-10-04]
enclosure/rele-esp12f_pcb.step
66.5 x 49.0 x 20.6 mm
ESP_12E001_cp
C_0603_1608Metric x 4
FUSE-TH_L8.4-W4.0-P5.08-D0.6
SW-SMD_4P-L5.1-W5.1-P3.70-LS6.5-TL_H1.5 x 2
SOT-23
LED_0603_1608Metric x 2
TerminalBlock_Phoenix_MKDS-1,5-3-5.08_1x03_P5.08mm_Horizontal
R_0603_1608Metric x 9
D_SOD-123
C_0805_2012Metric x 2
CP_Radial_D63mm_P250mm
SOT-223
RELAY-TH_G5RL-1A-E-HR
Converter_ACDC_Hi-Link_HLK-PMxx
RV_Disc_D7mm_W34mm_P5mm
rele-esp12f_PCB

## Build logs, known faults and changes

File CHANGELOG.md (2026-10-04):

# Changelog

All notable hardware revisions are documented here, together with the engineering rationale behind each change.

## [firmware 1.0.0] — 2026-10-04

### Added
- **First firmware for the board** in [`firmware/`](firmware/) (PlatformIO, Arduino core for ESP8266). The relay is controlled over Wi-Fi only: manual on/off, state-change timer, cyclic ON/OFF routine and up to 16 weekly schedules (NTP + POSIX time zone). Web interface, JSON REST API with Digest authentication, setup access point with captive portal, mDNS and OTA updates (ArduinoOTA and browser upload).
- **Hardware-aware defaults**: GPIO5 is driven low before anything else runs, the relay state is only written to flash when it changes (never during the cyclic routine), and each routine phase is at least 5 s.

## [v3] — 2026-10-03

### Changed
- **Omron G5RL-1A-E-HR DC5 relay** (SPST-NO, 16 A / 250 VAC, LCSC C113250) instead of the SRD-05VDC-SL-C. It uses the `Relay_SPST_Omron_G2RL-1A-E` footprint, which has the same 6-hole Ø1.3 mm pattern given in the G5RL-1A-E datasheet. As an "-E" high-capacity model, each contact comes out on two pins and the manufacturer requires both to be used; on the board each pair is joined by the power trace.
- **Coil and contacts 20 mm apart** (8 mm internal distance, reinforced insulation). The clearance exception required by the SRD relay is gone.
- **66.5 × 49 mm board** to fit the 29 × 12.7 mm relay.
- **J3 powered at 5 V** (pin 1 = GND, pin 2 = 5 V). Injecting 3.3 V into the AMS1117 output forward-biased its internal output→input diode and loaded the 5 V rail. Besides, the 3.3 V pin of a typical USB-serial adapter cannot supply the ESP8266 current peaks. The +3V3 branch to J3, which split the GND plane under the module, was removed.
- **Load current up to 10 A**: L_IN and L_OUT duplicated on both sides (2 × 2.5 mm). Per IPC-2221 (35 µm, external layer) they carry about 12 A with a 20 °C rise.
- **Mains copper moved away from the edge**: F1 and RV1 shifted by 2 mm and N and L_F re-routed. The minimum distance to the edge went from 1.3 to 2.0 mm.
- **Silkscreen and schematic labels in English** ("DANGER: 110 VAC", section titles, LED values). Schematic title block updated to revision v3.

### Added
- **C7 and C8 (100 nF)** on EN and RST: together with R1/R2 they form a ~1 ms RC delay at start-up, as recommended by Espressif.
- **C9 (10 µF X5R 0603, C19702)** next to the ESP-12F VCC pin, in parallel with C5 (100 nF), to cover the transmit current peaks.
- PDF datasheet and user guide, and a 3D-printable enclosure.

### Fixed
- **K1 design rule removed.** It reduced the clearance to 2 mm for any object inside the K1 courtyard and, being the last matching rule, overrode the 4 mm mains/low-voltage rule in that area.
- **Net-(D3-A) trace moved out of the MH1 washer area.** It ran 0.35 mm from the hole, under the hardware. No signal trace or pad now enters a Ø5 mm circle around MH1/MH2.
- **L_IN widened to 2.5 mm** (previously 2.0 mm), matching L_OUT.
- **Assembly attributes**: K1 and J3 marked as THT and C7/C8 as SMD, so they are exported correctly to the CPL.

## [v2] — 2026-09-30

### Changed
- **Board size reduced from 66 × 66 mm to 66.5 × 44 mm** (−33 % area), with all components on the top side.
- **New layout**: supply and ESP-12F in the top strip (antenna at the edge), mains zone at the bottom left and low voltage at the bottom right.
- **110 VAC nominal voltage** (07D221K varistor).
- **J3 as a 2×3 header**, 2.54 mm pitch (previously 1×6): half the size and ~10 mm away from the antenna.
- Board nets synchronized with the schematic. The MAINS and PWR net classes were extended to the new names.
- GND planes on both sides, only in the low-voltage zone and geometrically ≥ 4.5 mm away from mains copper.

### Manufacturing
- **Full assembly at JLCPCB**, including the THT parts: J1 (KANGNEX WJ500V-5.08-3P, C72334) and J3 (C65114).
- **F1 replaced with a Reomax MTS0500A** (T500mA 250 V, C2762401), because the Littelfuse 39505000440 was out of stock; same footprint.
- **CPL using the pad center** (JLCPCB convention). U2 and K1 previously used the body center and were offset by 3.8 and 1.4 mm.
- **Adjusted drill sizes**: J1 from Ø1.3 to Ø1.5 mm and RV1 from Ø0.6 to Ø1.0 mm, according to the manufacturers' lead dimensions. Copper pads are unchanged.
- STEP models for SW1/SW2, F1 and K1 in `3dmodels/`, referenced through `${KIPRJMOD}`.

### Fixed
- Silkscreen: 19 reference designators and the version text were repositioned; they overlapped, sat next to the wrong component or fell outside the board edge.

## [v1] — 2026-09-25

- Initial design: ESP-12F Wi-Fi relay module with HLK-PM01 supply, SRD-05VDC-SL-C relay and custom mains/low-voltage isolation rules.

[v3]: https://github.com/techmiguel/smartRele/releases/tag/v3
[v2]: https://github.com/techmiguel/smartRele/tree/v2
[v1]: https://github.com/techmiguel/smartRele/tree/v1

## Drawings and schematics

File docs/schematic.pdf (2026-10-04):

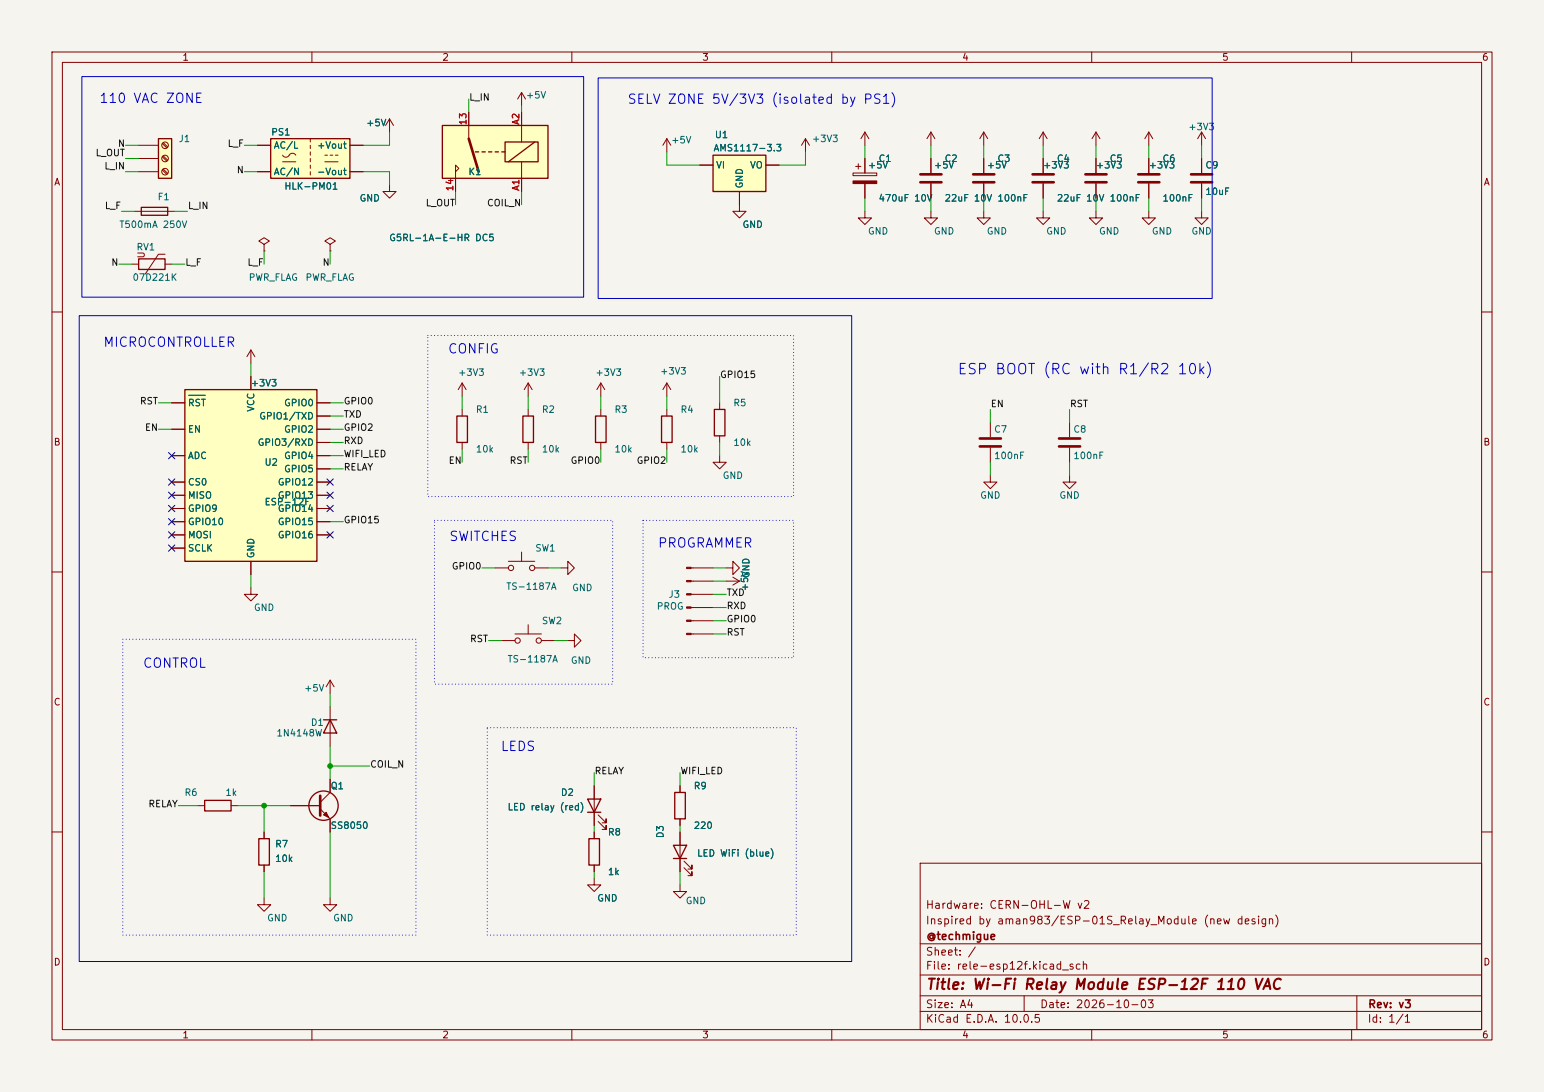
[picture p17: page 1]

SELV ZONE 5V/3V3 (isolated by PS1)

ESP BOOT (RC with R1/R2 10k)

Hardware: CERN-OHL-W v2
Inspired by aman983/ESP-01S_Relay_Module (new design)
@techmigue
Sheet: /
File: rele-esp12f.kicad_sch
Title: Wi-Fi Relay Module ESP-12F 110 VAC

Size: A4 | Rev: v3
KiCad E.D.A. 10.0.5 | Id: 1/1

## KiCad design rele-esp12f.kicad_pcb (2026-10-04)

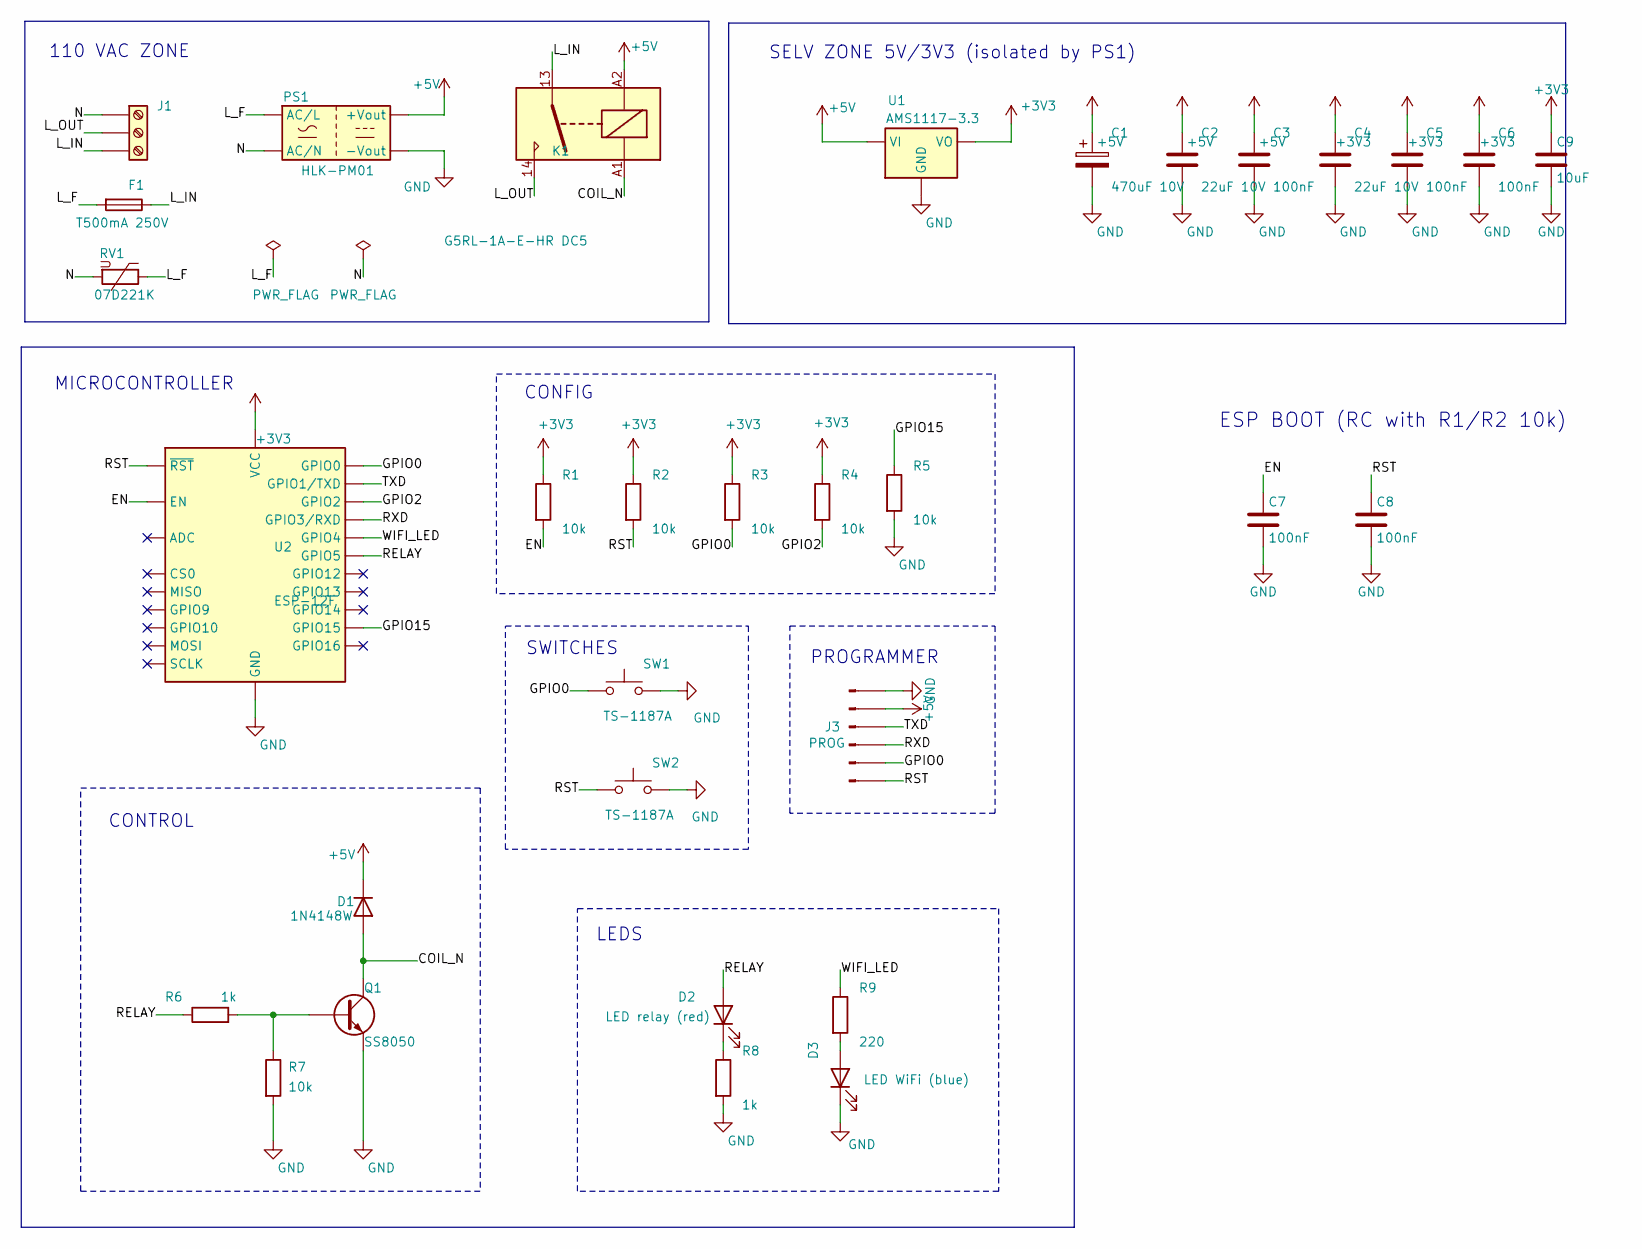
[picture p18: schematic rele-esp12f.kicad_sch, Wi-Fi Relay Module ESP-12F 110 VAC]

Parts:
C1: 470uF 10V; CP_Radial_D6.3mm_P2.50mm; LCSC C112505
C2, C4: 22uF 10V; C_0805_2012Metric; LCSC C45783
C3, C5, C6, C7, C8: 100nF; C_0603_1608Metric; LCSC C14663
C9: 10uF; C_0603_1608Metric; LCSC C19702
D1: 1N4148W; D_SOD-123; LCSC C81598
D2: LED relay (red); LED_0603_1608Metric; LCSC C2286
D3: LED WiFi (blue); LED_0603_1608Metric; LCSC C51933294
F1: T500mA 250V; Fuse_Littelfuse_395Series; LCSC C2762401
J1: N / L_OUT / L_IN; TerminalBlock_Phoenix_MKDS-1,5-3-5.08_1x03_P5.08mm_Horizont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; LCSC C72334
J3: PROG; PinHeader_2x03_P2.54mm_Vertical; LCSC C65114
K1: G5RL-1A-E-HR DC5; Relay_SPST_Omron_G2RL-1A-E; LCSC C113250
PS1: HLK-PM01; Converter_ACDC_Hi-Link_HLK-PMxx; LCSC C209903
Q1: SS8050; SOT-23; LCSC C2150
R1, R2, R3, R4, R5, R7: 10k; R_0603_1608Metric; LCSC C25804
R6, R8: 1k; R_0603_1608Metric; LCSC C21190
R9: 220; R_0603_1608Metric; LCSC C22962
RV1: 07D221K; RV_Disc_D7mm_W3.4mm_P5mm; LCSC C49072913
SW1, SW2: TS-1187A; SW_Push_1P1T_XKB_TS-1187A; LCSC C318884
U1: AMS1117-3.3; SOT-223-3_TabPin2; LCSC C6186
U2: ESP-12F; ESP-12E; LCSC C82891

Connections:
+3V3: C4.1, C5.1, C6.1, C9.1, R1.1, R2.1, R3.1, R4.1, U1.2 (VO), U2.8 (VCC)
+5V: C1.1, C2.1, C3.1, D1.1 (K), J3.2, K1.A2, PS1.4 (+Vout), U1.3 (VI)
/COIL_N: D1.2 (A), K1.A1, Q1.3 (C)
/EN: C7.1, R1.2, U2.3 (EN)
/GPIO0: J3.5, R3.2, SW1.1, U2.18 (GPIO0)
/GPIO2: R4.2, U2.17 (GPIO2)
/GPIO15: R5.1, U2.16 (GPIO15)
/L_F: F1.2, PS1.1 (AC/L), RV1.1
/L_IN: F1.1, J1.3, K1.13
/L_OUT: J1.2, K1.14
/N: J1.1, PS1.2 (AC/N), RV1.2
/RELAY: D2.2 (A), R6.1, U2.20 (GPIO5)
/RST: C8.1, J3.6, R2.2, SW2.1, U2.1 (~RST)
/RXD: J3.4, U2.21 (GPIO3/RXD)
/TXD: J3.3, U2.22 (GPIO1/TXD)
/WIFI_LED: R9.1, U2.19 (GPIO4)
GND: C1.2, C2.2, C3.2, C4.2, C5.2, C6.2, C7.2, C8.2, C9.2, D3.1 (K), J3.1, PS1.3 (-Vout), Q1.2 (E), R5.2, R7.2, R8.2, SW1.2, SW2.2, U1.1 (GND), U2.15 (GND)
unnamed: D2.1 (K), R8.1
unnamed: D3.2 (A), R9.2
unnamed: Q1.1 (B), R6.2, R7.1

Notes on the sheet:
PROGRAMMER
MICROCONTROLLER
110 VAC ZONE
CONFIG
SELV ZONE 5V/3V3 (isolated by PS1)
LEDS
SWITCHES
CONTROL
ESP BOOT (RC with R1/R2 10k)

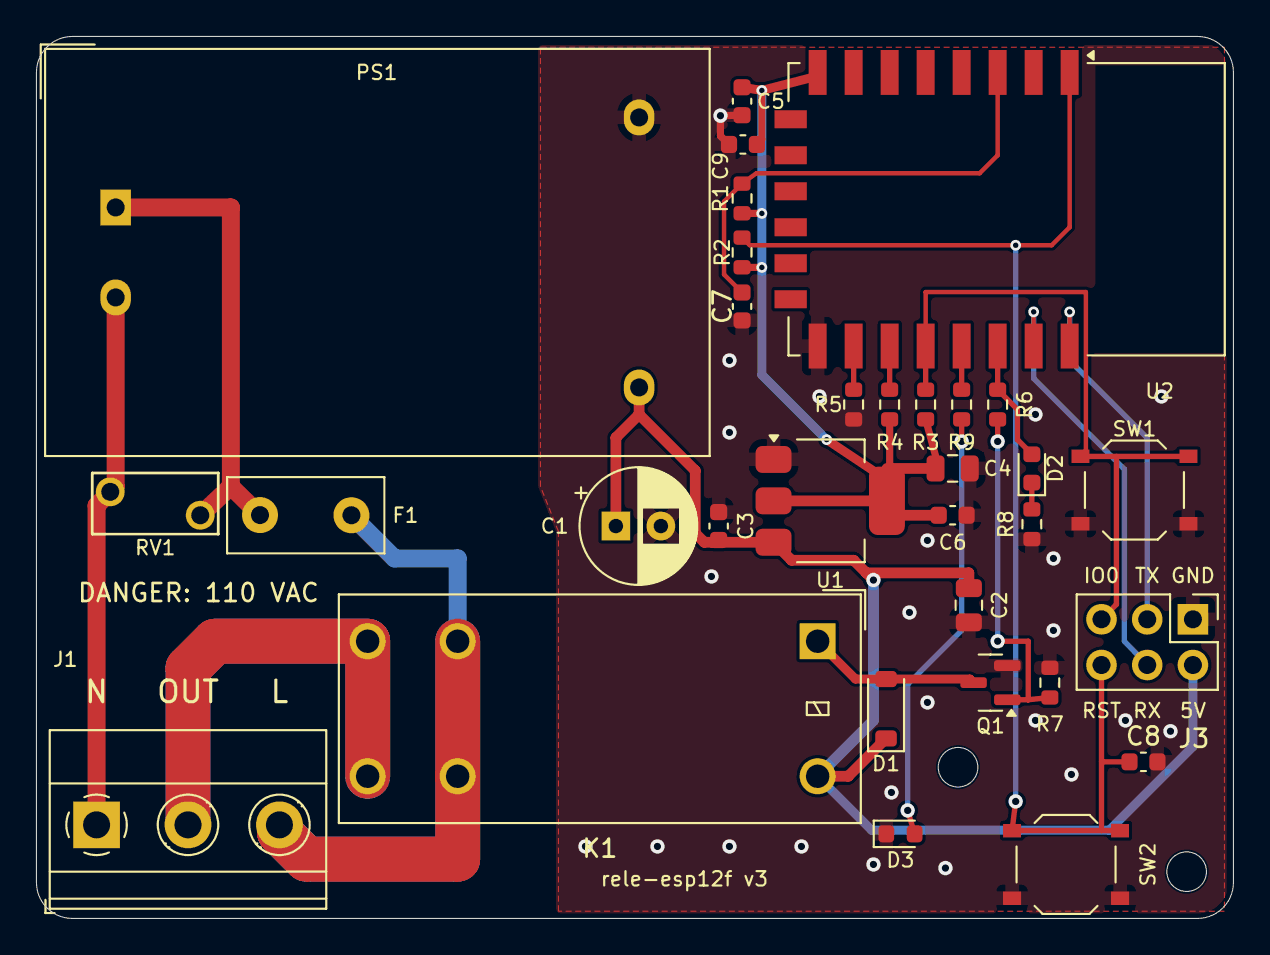
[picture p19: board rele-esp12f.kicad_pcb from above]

Board: 2 copper layers, 66.5 x 49.0 mm, 34 parts (0 on the bottom side), 20 nets.

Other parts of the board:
MH1, MH2: M2; MountingHole_2.2mm_M2

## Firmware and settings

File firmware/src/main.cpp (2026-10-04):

// SmartRele · rele-esp12f — firmware v1
//
// The relay is controlled over Wi-Fi only: on/off, state-change timer, cyclic ON/OFF
// routine and weekly schedules. Web interface and REST API on port 80.

#include <Arduino.h>

#include "board.h"
#include "network.h"
#include "relay.h"
#include "scheduler.h"
#include "settings.h"
#include "web.h"

void setup() {
  // First of all: relay at rest. R7 already keeps it open while the pin is high-impedance;
  // here the pin is driven low before anything else runs.
  digitalWrite(PIN_RELAY, LOW);
  pinMode(PIN_RELAY, OUTPUT);

  Serial.begin(115200);
  Serial.println();
  Serial.printf("\n[sys] SmartRele %s · reset reason: %s\n", FW_VERSION, ESP.getResetReason().c_str());

  if (!store::begin()) Serial.println(F("[fs] ERROR: no file system"));
  store::load();

  relay::begin();
  network::begin();
  scheduler::begin();
  web::begin();
  Serial.printf("[sys] ready: http://%s.local/\n", network::hostname().c_str());
}

void loop() {
  network::loop();
  web::loop();
  relay::loop();
  scheduler::loop();
}

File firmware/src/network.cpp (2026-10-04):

#include "network.h"

#include <ArduinoOTA.h>
#include <DNSServer.h>
#include <ESP8266WiFi.h>
#include <ESP8266mDNS.h>

#include "board.h"
#include "settings.h"

namespace {
String host;
String ap;
DNSServer dns;
bool apOn = false;
bool otaStarted = false;
uint32_t disconnectedSince = 0;
uint32_t restartAt = 0;
uint32_t buttonDownAt = 0;
WiFiEventHandler onGotIp, onDisconnected;

void startAp() {
  if (apOn) return;
  WiFi.mode(settings.wifiSsid[0] ? WIFI_AP_STA : WIFI_AP);
  WiFi.softAPConfig(IPAddress(192, 168, 4, 1), IPAddress(192, 168, 4, 1),
                    IPAddress(255, 255, 255, 0));
  WiFi.softAP(ap.c_str(), network::AP_PASSWORD);
  dns.setErrorReplyCode(DNSReplyCode::NoError);
  dns.start(53, "*", WiFi.softAPIP());
  apOn = true;
  Serial.printf("[wifi] AP \"%s\" up at %s\n", ap.c_str(), WiFi.softAPIP().toString().c_str());
}

void stopAp() {
  if (!apOn) return;
  dns.stop();
  WiFi.softAPdisconnect(true);
  WiFi.mode(WIFI_STA);
  apOn = false;
  Serial.println(F("[wifi] AP stopped"));
}

void startOta() {
  if (otaStarted) return;
  ArduinoOTA.setHostname(host.c_str());
  if (settings.adminPass[0]) ArduinoOTA.setPassword(settings.adminPass);
  ArduinoOTA.onStart([] { Serial.println(F("[ota] start")); });
  ArduinoOTA.onEnd([] { Serial.println(F("[ota] end")); });
  ArduinoOTA.onError([](ota_error_t e) { Serial.printf("[ota] error %u\n", e); });
  ArduinoOTA.begin(false);  // mDNS is handled by this module
  otaStarted = true;
}

// Blue LED: steady = connected; fast blink = setup AP;
// short flash every second = looking for the network; very fast blink = SW1 about to erase.
void updateLed() {
  uint32_t t = millis();
  bool on;
  if (buttonDownAt && t - buttonDownAt > 3000) on = (t / 60) & 1;
  else if (WiFi.isConnected()) on = true;
  else if (apOn) on = (t / 250) & 1;
  else on = (t % 1000) < 80;
  digitalWrite(PIN_WIFI_LED, on ? HIGH : LOW);
}

void handleButton() {
  bool pressed = digitalRead(PIN_BUTTON) == LOW;
  if (pressed && !buttonDownAt) buttonDownAt = millis() | 1;
  if (!pressed) buttonDownAt = 0;
  if (buttonDownAt && millis() - buttonDownAt > network::BUTTON_RESET_MS) {
    Serial.println(F("[btn] erasing Wi-Fi settings"));
    settings.wifiSsid[0] = 0;
    settings.wifiPass[0] = 0;
    store::save();
    buttonDownAt = 0;
    network::requestRestart(100);
  }
}
}  // namespace

namespace network {

const String& hostname() { return host; }
const String& apSsid() { return ap; }
bool staConnected() { return WiFi.isConnected(); }
bool apActive() { return apOn; }
bool captivePortal() { return apOn && !WiFi.isConnected(); }

void requestRestart(uint32_t delayMs) { restartAt = (millis() + delayMs) | 1; }

void begin() {
  pinMode(PIN_WIFI_LED, OUTPUT);
  digitalWrite(PIN_WIFI_LED, LOW);
  pinMode(PIN_BUTTON, INPUT);  // external R3 to 3.3 V

  char buf[24];
  snprintf(buf, sizeof(buf), "smartrele-%06x", ESP.getChipId());
  host = buf;
  snprintf(buf, sizeof(buf), "SmartRele-%06X", ESP.getChipId());
  ap = buf;
  if (!settings.deviceName[0]) strlcpy(settings.deviceName, host.c_str(), sizeof(settings.deviceName));

  WiFi.persistent(false);  // credentials live in config.json, not in the SDK flash area
  WiFi.setAutoReconnect(true);
  WiFi.hostname(host);
  WiFi.setSleepMode(WIFI_NONE_SLEEP);  // low web latency; power draw is not critical

  onGotIp = WiFi.onStationModeGotIP([](const WiFiEventStationModeGotIP& e) {
    Serial.printf("[wifi] connected to \"%s\", IP %s\n", settings.wifiSsid, e.ip.toString().c_str());
    disconnectedSince = 0;
  });
  onDisconnected = WiFi.onStationModeDisconnected([](const WiFiEventStationModeDisconnected&) {
    if (!disconnectedSince) disconnectedSince = millis() | 1;
  });

  if (settings.wifiSsid[0]) {
    WiFi.mode(WIFI_STA);
    WiFi.begin(settings.wifiSsid, settings.wifiPass);
    disconnectedSince = millis() | 1;
    Serial.printf("[wifi] connecting to \"%s\"\n", settings.wifiSsid);
  } else {
    startAp();
  }

  MDNS.begin(host.c_str());
  MDNS.addService("http", "tcp", 80);
  startOta();
}

void loop() {
  if (apOn) dns.processNextRequest();
  MDNS.update();
  ArduinoOTA.handle();
  handleButton();
  updateLed();

  if (settings.wifiSsid[0]) {
    bool connected = WiFi.isConnected();
    // No network for a minute: rescue AP (the station keeps retrying).
    if (!connected && !apOn && disconnectedSince && millis() - disconnectedSince > STA_FALLBACK_MS)
      startAp();
    // Network back: close the AP unless someone is connected to it.
    if (connected && apOn && WiFi.softAPgetStationNum() == 0) stopAp();
  }

  if (restartAt && static_cast<int32_t>(millis() - restartAt) >= 0) {
    Serial.println(F("[sys] restarting"));
    Serial.flush();
    ESP.restart();
  }
}

}  // namespace network

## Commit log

2026-09-30 Initial v1 design
    [BOM_JLCPCB.csv, BOM_soldadura_manual.csv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]
2026-09-30 Adjust layout of mains traces L_IN, N and L_OUT
    [rele-esp12f.kicad_pcb]
2026-09-30 v2 redesign: 66.5 x 44 mm board and 110 VAC
    New layout (PS1 and ESP-12F at the top, mains zone at the bottom left
    and low voltage at the bottom right), J3 as a 2x3 header, board nets
    synchronized with the schematic and MAINS/PWR net classes extended to
    the new names, GND planes on both sides restricted to the low-voltage
    zone. BOM, CPL, gerbers, renders and README updated.
    [BOM_JLCPCB.csv, BOM_soldadura_manual.csv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]
2026-09-30 Fix silkscreen placement (references and texts)
    19 reference designators and the version text were repositioned; they
    overlapped other texts or pads, sat next to the wrong component
    (R3/R4/R9 visually swapped) or fell outside the board edge (D2, D3,
    R8, SW2, J1, J3). No component or trace was moved.
    DRC: 13 silkscreen overlaps -> 0; 0 errors, 0 unconnected.
    Gerbers regenerated: only F_Silkscreen changes; the .gbrjob now
    includes F_Paste. Top render updated.
    [rele-esp12f-B_Cu.gbl, rele-esp12f-B_Mask.gbs, rele-esp12f-B_Silkscreen.gbo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]
2026-09-30 Prepare full assembly at JLCPCB
    - CPL: U2 and K1 use the pad center (JLCPCB convention); they used
    the body center before and were offset by 3.8 and 1.4 mm.
    - J1 (KANGNEX WJ500V-5.08-3P terminal block, C72334) and J3 (BOOMELE
    2x3 header, C65114) are now assembled by JLCPCB; the manual BOM only
    lists MH1/MH2.
    - F1: Littelfuse 39505000440 (10 pcs in stock) replaced with Reomax
    MTS0500A (C2762401), T500mA 250V, same footprint and drill.
    - Drills: J1 from 1.3 to 1.5 mm (KANGNEX recommendation, 0.9x0.8 mm
    pin) and RV1 from 0.6 to 1.0 mm (0.6+-0.1 mm lead). Pads unchanged;
    DRC 0 errors. Only the PTH.drl file changes.
    [BOM_JLCPCB.csv, BOM_soldadura_manual.csv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]
2026-09-30 Add 3D models for SW1/SW2 and F1
    The KiCad 10 library does not include STEP models for the TS-1187A or
    the Littelfuse 395 fuse, and the board pointed to KiCad 6/7 .wrl paths.
    They were downloaded from EasyEDA/LCSC with easyeda2kicad (C318884 and
    C2762401, the Reomax MTS0500A fuse in the BOM) and stored in 3dmodels/
    with a ${KIPRJMOD} path. Fuse offset +2.54 mm in X (EasyEDA origin at
    the center, KiCad origin at pin 1). Top render updated.
    [Fuse_Reomax_MTS_C2762401.step, SW_TS-1187A_C318884.step, rele-esp12f.kicad_pcb]
2026-09-30 README: document full assembly at JLCPCB
    THT parts table with LCSC numbers, fuse change, CPL using the pad
    center, adjusted J1 and RV1 drills, commands to regenerate gerbers and
    renders, and updated DRC status.
2026-10-04 v3 revision: Omron G5RL relay, 10 A load and complete documentation
    Hardware
    - Omron G5RL-1A-E-HR relay (16 A, reinforced insulation) instead of
    the SRD-05VDC; 66.5 x 49 mm board.
    - Power path duplicated on both sides (2 x 2.5 mm) for 10 A.
    - J3 powered at 5 V; RC delay on EN/RST (C7, C8) and 10 uF
    decoupling next to the ESP-12F (C9).
    - Mains copper >= 2.0 mm from the edge; K1 rule removed so the 4 mm
    mains/low-voltage clearance applies across the whole board.
    - Gerbers, drill files, BOM, CPL, renders and schematic regenerated.
    Repository
    - Restructured README, CHANGELOG and CERN-OHL-W-2.0 license.
    - PDF datasheet and user guide with its generator script.
    -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
    [BOM_JLCPCB.csv, BOM_soldadura_manual.csv, Relay_Omron_G5RL-1A-E-HR_C113250.step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]
2026-10-04 Translate the repository to English
    - README, CHANGELOG and enclosure README rewritten in English.
    - Folders and files renamed: fabrication/, enclosure/, docs/schematic.pdf,
    docs/pcb_top.png, docs/pcb_bottom.png, scripts/generate_datasheet.py.
    - Datasheet and user guide regenerated in English (document rev. B).
    - Silkscreen "DANGER: 110 VAC", schematic notes, LED values, design rule
    names and the "Assembly" field translated; schematic title block set
    to revision v3. Gerbers, ZIP, renders and schematic PDF regenerated.
    - Enclosure script translated and lid label changed to "RELAY"; STL,
    STEP, FreeCAD document and renders regenerated.
    DRC: 0 errors, 0 unconnected (29 warnings, unchang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
    [BOM_JLCPCB.csv, chasis_rele-esp12f.FCStd, chasis_rele-esp12f_ensamblado.step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]
2026-10-04 Add ESP8266 firmware: Wi-Fi relay control, timer, cyclic routine and schedules
    First firmware for the board (PlatformIO, Arduino core for ESP8266). The relay
    is controlled over Wi-Fi only:
    - manual on/off;
    - state-change timer (on/off/toggle after 1 s to 7 days);
    - cyclic ON/OFF routine (5 s to 24 h per phase, resumes after a power cut);
    - up to 16 weekly schedules, NTP time with a POSIX time zone.
    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

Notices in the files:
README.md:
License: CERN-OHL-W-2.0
